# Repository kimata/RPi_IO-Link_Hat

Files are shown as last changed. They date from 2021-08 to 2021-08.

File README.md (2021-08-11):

# Raspberry Pi IO-LINK Hat

## 概要

Raspberry Pi と IO-Link 基板を接続するためのブリッジ基板です．

24V 電源で動作し，IO-Link 機器と Raspberry Pi への電源の供給を行います．

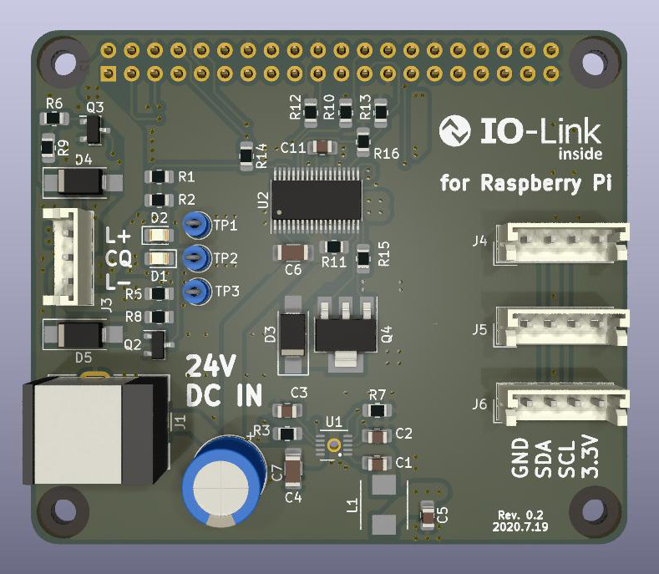
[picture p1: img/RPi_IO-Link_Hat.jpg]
Raspberry Pi IO-LINK Hat


## 使用部品

使用している主な部品は以下の通りです．

| リファレンス | Mouser # |
| --- | --- |
| D3 | 512-S100 |
| D4, D5 | 755-PTZTFTE2536B |
| J1 | 490-PJ-063AH |
| L1 | 810-SPM5030VT-2R2M-D |
| Q2, Q3 | 757-T2N7002BKLM |
| Q4 | 512-FQT7N10LTF |
| U1 | 584-LT8609AJDDM-5#TR |
| U2 | 584-LTC2874IFE#PBF |

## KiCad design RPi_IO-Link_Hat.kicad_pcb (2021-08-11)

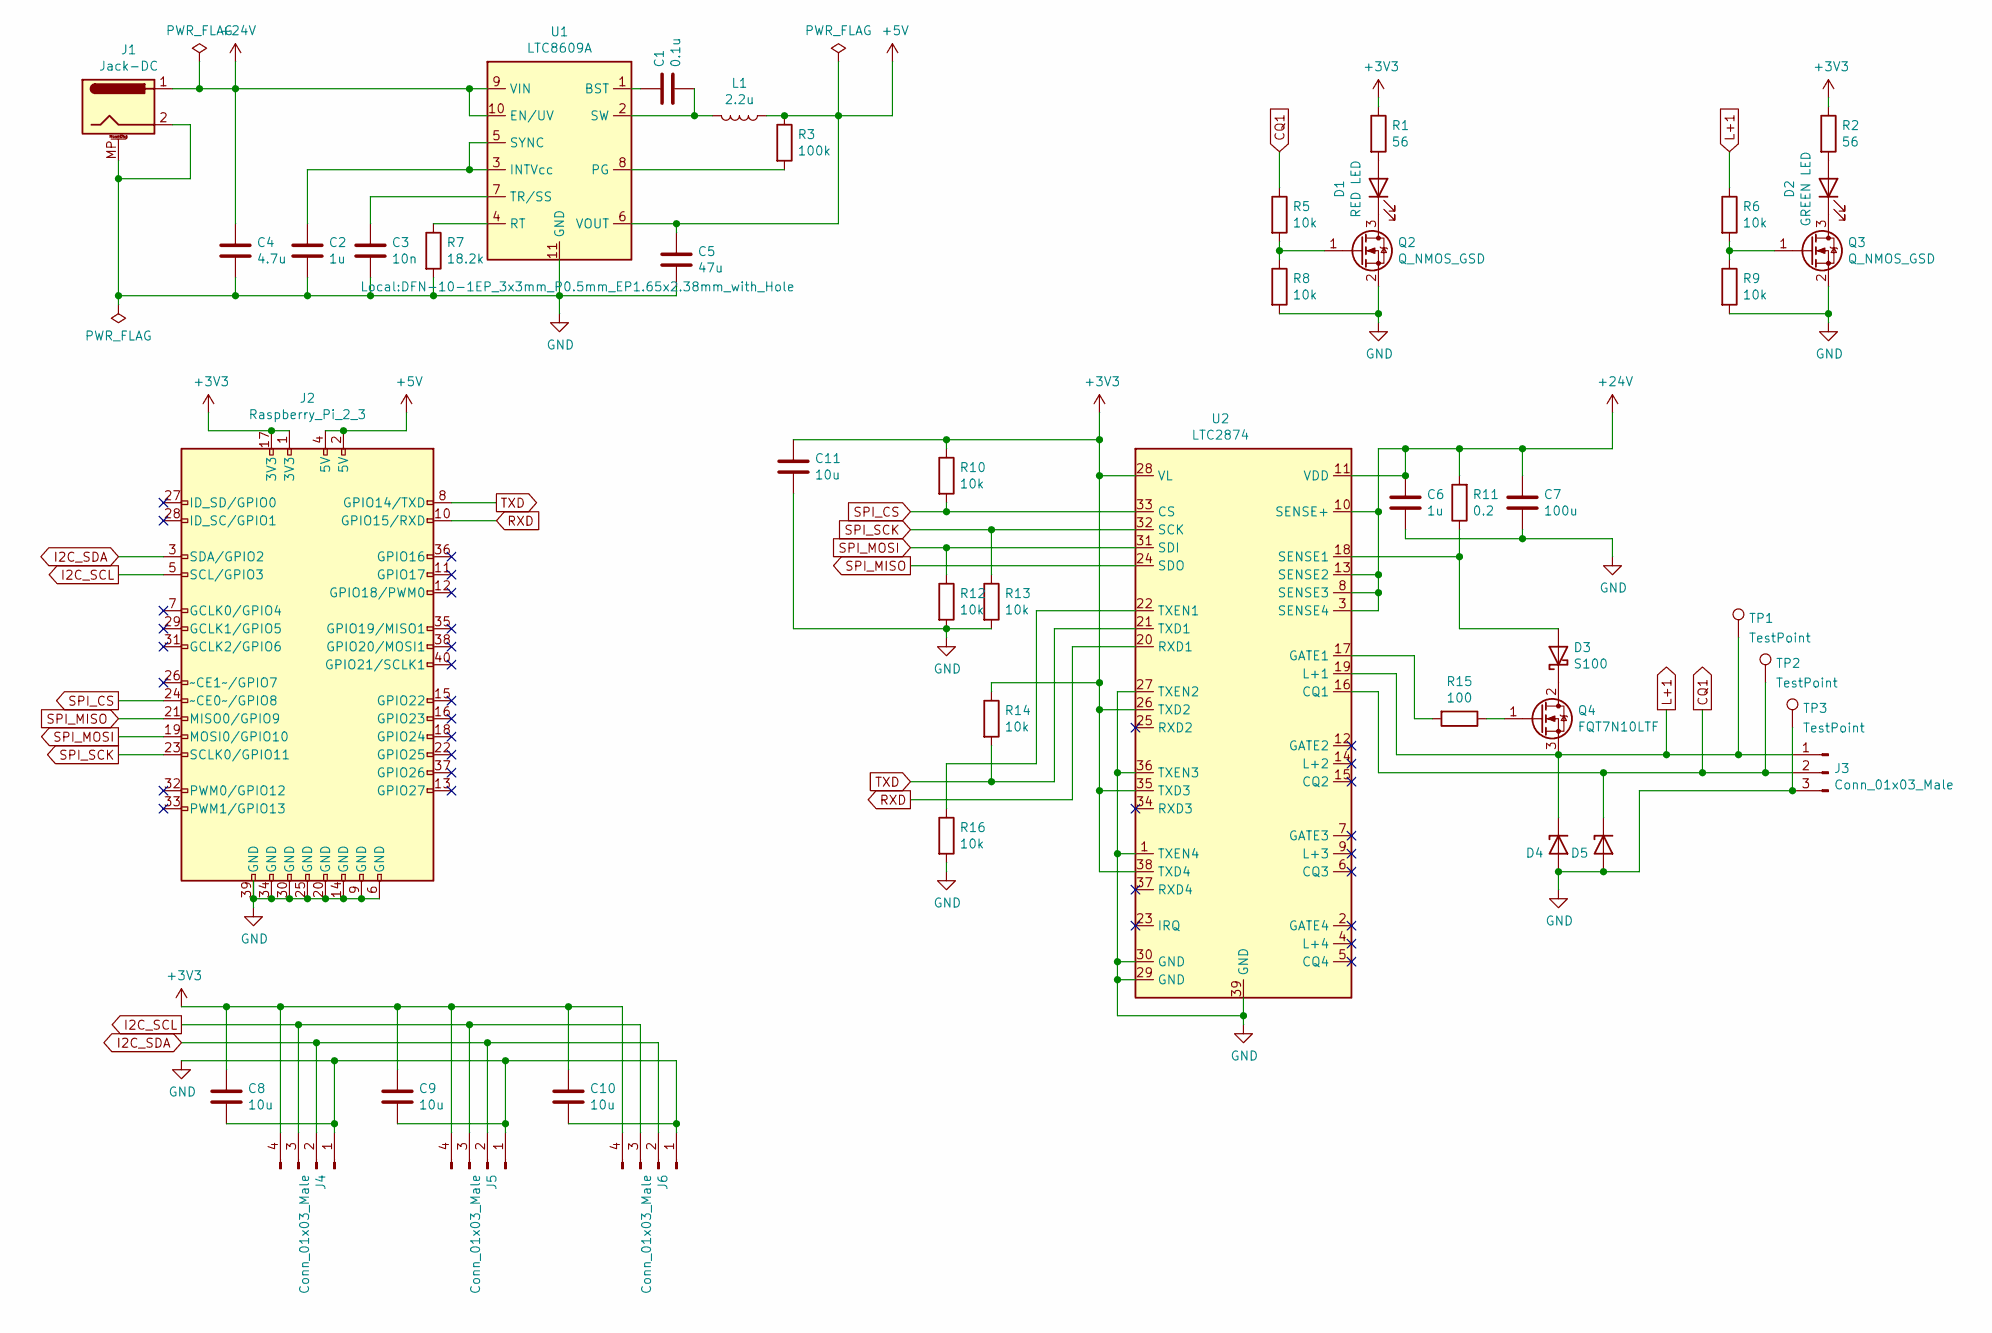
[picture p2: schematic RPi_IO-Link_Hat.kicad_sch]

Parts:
C1: 0.1u; C_0805_2012Metric_Pad1.18x1.45mm_HandSolder; Mouser 81-GCJ21BL81H104KA1L
C2: 1u; C_0805_2012Metric_Pad1.18x1.45mm_HandSolder; Mouser 81-GRM219R61A105MA1D
C3: 10n; C_0805_2012Metric_Pad1.18x1.45mm_HandSolder; Mouser 81-GCJ216R71E103KA1D
C4: 4.7u; C_1206_3216Metric_Pad1.33x1.80mm_HandSolder; Mouser 81-GRM31CR71H475KA2K
C5: 47u; C_0805_2012Metric_Pad1.18x1.45mm_HandSolder; Mouser 81-GRT21BR60J476ME3L
C6: 1u; C_1206_3216Metric_Pad1.33x1.80mm_HandSolder; Mouser 81-GRT31MC81H105KE1L
C7: 100u; CP_Radial_D8.0mm_P3.50mm; Mouser 667-EEU-EB1H101SJ
C8, C9, C10, C11: 10u; C_0805_2012Metric_Pad1.18x1.45mm_HandSolder; Mouser 81-GRM219R60J106KE9D
D1: RED LED; LED_0805_2012Metric_Pad1.15x1.40mm_HandSolder; Mouser 720-LGR971-KN-1
D2: GREEN LED; LED_0805_2012Metric_Pad1.15x1.40mm_HandSolder; Mouser 720-LSR976-NR-1
D3: S100; D_SMA_Handsoldering; Mouser 512-S100
D4, D5: PTZTFTE2536B; D_SMA_Handsoldering; Mouser 755-PTZTFTE2536B
J1: Jack-DC; BarrelJack_CUI_PJ-063AH_Horizontal; Mouser 490-PJ-063AH
J2: Raspberry_Pi_2_3; PinSocket_2x20_P2.54mm_Vertical
J3: Conn_01x03_Male; JST_EH_B3B-EH-A_1x03_P2.50mm_Vertical
J4, J5, J6: Conn_01x03_Male; JST_EH_B4B-EH-A_1x04_P2.50mm_Vertical
L1: 2.2u; L_TDK_SPM5030VT; Mouser 810-SPM5030VT-2R2M-D
Q2, Q3: Q_NMOS_GSD; SOT-23; Mouser 757-T2N7002BKLM
Q4: FQT7N10LTF; SOT-223-3_TabPin2_empty; Mouser 512-FQT7N10LTF
R1, R2: 56; R_0805_2012Metric_Pad1.20x1.40mm_HandSolder; Mouser 667-ERJ-6ENF56R0V
R3: 100k; R_0805_2012Metric_Pad1.20x1.40mm_HandSolder; Mouser 667-ERJ-6GEYJ104V
R5, R6, R8, R9, R10, R12, R13, R14, R16: 10k; R_0805_2012Metric_Pad1.20x1.40mm_HandSolder; Mouser 667-ERJ-6ENF1002V
R7: 18.2k; R_0805_2012Metric_Pad1.20x1.40mm_HandSolder; Mouser 667-ERJ-6ENF1822V
R11: 0.2; R_0805_2012Metric_Pad1.20x1.40mm_HandSolder; Mouser 667-ERJ-6BSFR20V
R15: 100; R_0805_2012Metric_Pad1.20x1.40mm_HandSolder; Mouser 667-ERJ-6ENF1000V
TP1, TP2, TP3: TestPoint; TestPoint_Loop_D1.80mm_Drill1.0mm_Beaded
U1: LTC8609A; DFN-10-1EP_3x3mm_P0.5mm_EP1.65x2.38mm_with_Hole; Mouser 584-LT8609AJDDM-5#TR
U2: LTC2874; TSSOP-38_4.4x9.7mm_P0.5mm_with_Hole; Mouser 584-LTC2874IFE#PBF

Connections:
+3V3: C8.1, C9.1, C10.1, C11.1, J2.1 (3V3), J2.17 (3V3), J4.4, J5.4, J6.4, R1.1, R2.1, R10.1, R14.1, U2.26 (TXD2), U2.28 (VL), U2.35 (TXD3), U2.38 (TXD4)
+5V: C5.1, J2.2 (5V), J2.4 (5V), L1.1, R3.1, U1.6 (VOUT)
+24V: C4.1, C6.1, C7.1, J1.1, R11.2, U1.9 (VIN), U1.10 (EN/UV), U2.3 (SENSE4), U2.8 (SENSE3), U2.10 (SENSE+), U2.11 (VDD), U2.13 (SENSE2)
CQ1: D5.1 (K), J3.2, R5.1, TP2.1, U2.16 (CQ1)
GND: C2.2, C3.2, C4.2, C5.2, C6.2, C7.2, C8.2, C9.2, C10.2, C11.2, D4.2 (A), D5.2 (A), J1.2, J1.MP (MountPin), J2.6 (GND), J2.9 (GND), J2.14 (GND), J2.20 (GND), J2.25 (GND), J2.30 (GND), J2.34 (GND), J2.39 (GND), J3.3, J4.1, J5.1, J6.1, Q2.2 (S), Q3.2 (S), R7.2, R8.2, R9.2, R12.2, R13.2, R16.2, TP3.1, U1.11 (GND), U2.1 (TXEN4), U2.27 (TXEN2), U2.29 (GND), U2.30 (GND), U2.36 (TXEN3), U2.39 (GND)
I2C_SCL: J2.5 (SCL/GPIO3), J4.3, J5.3, J6.3
I2C_SDA: J2.3 (SDA/GPIO2), J4.2, J5.2, J6.2
L+1: D4.1 (K), J3.1, Q4.3 (S), R6.1, TP1.1, U2.19 (L+1)
unnamed: C1.1, U1.1 (BST)
unnamed: C1.2, L1.2, U1.2 (SW)
unnamed: C2.1, U1.3 (INTVcc), U1.5 (SYNC)
unnamed: C3.1, U1.7 (TR/SS)
unnamed: D1.1 (K), Q2.3 (D)
unnamed: D1.2 (A), R1.2
unnamed: D2.1 (K), Q3.3 (D)
unnamed: D2.2 (A), R2.2
unnamed: D3.1 (K), Q4.2 (D)
unnamed: D3.2 (A), R11.1, U2.18 (SENSE1)
unnamed: Q2.1 (G), R5.2, R8.1
unnamed: Q3.1 (G), R6.2, R9.1
unnamed: Q4.1 (G), R15.1
unnamed: R3.2, U1.8 (PG)
unnamed: R7.1, U1.4 (RT)
unnamed: R15.2, U2.17 (GATE1)
unnamed: R16.1, U2.22 (TXEN1)
RXD: J2.10 (GPIO15/RXD), U2.20 (RXD1)
SPI_CS: J2.24 (~CE0~/GPIO8), R10.2, U2.33 (CS)
SPI_MISO: J2.21 (MISO0/GPIO9), U2.24 (SDO)
SPI_MOSI: J2.19 (MOSI0/GPIO10), R12.1, U2.31 (SDI)
SPI_SCK: J2.23 (SCLK0/GPIO11), R13.1, U2.32 (SCK)
TXD: J2.8 (GPIO14/TXD), R14.2, U2.21 (TXD1)

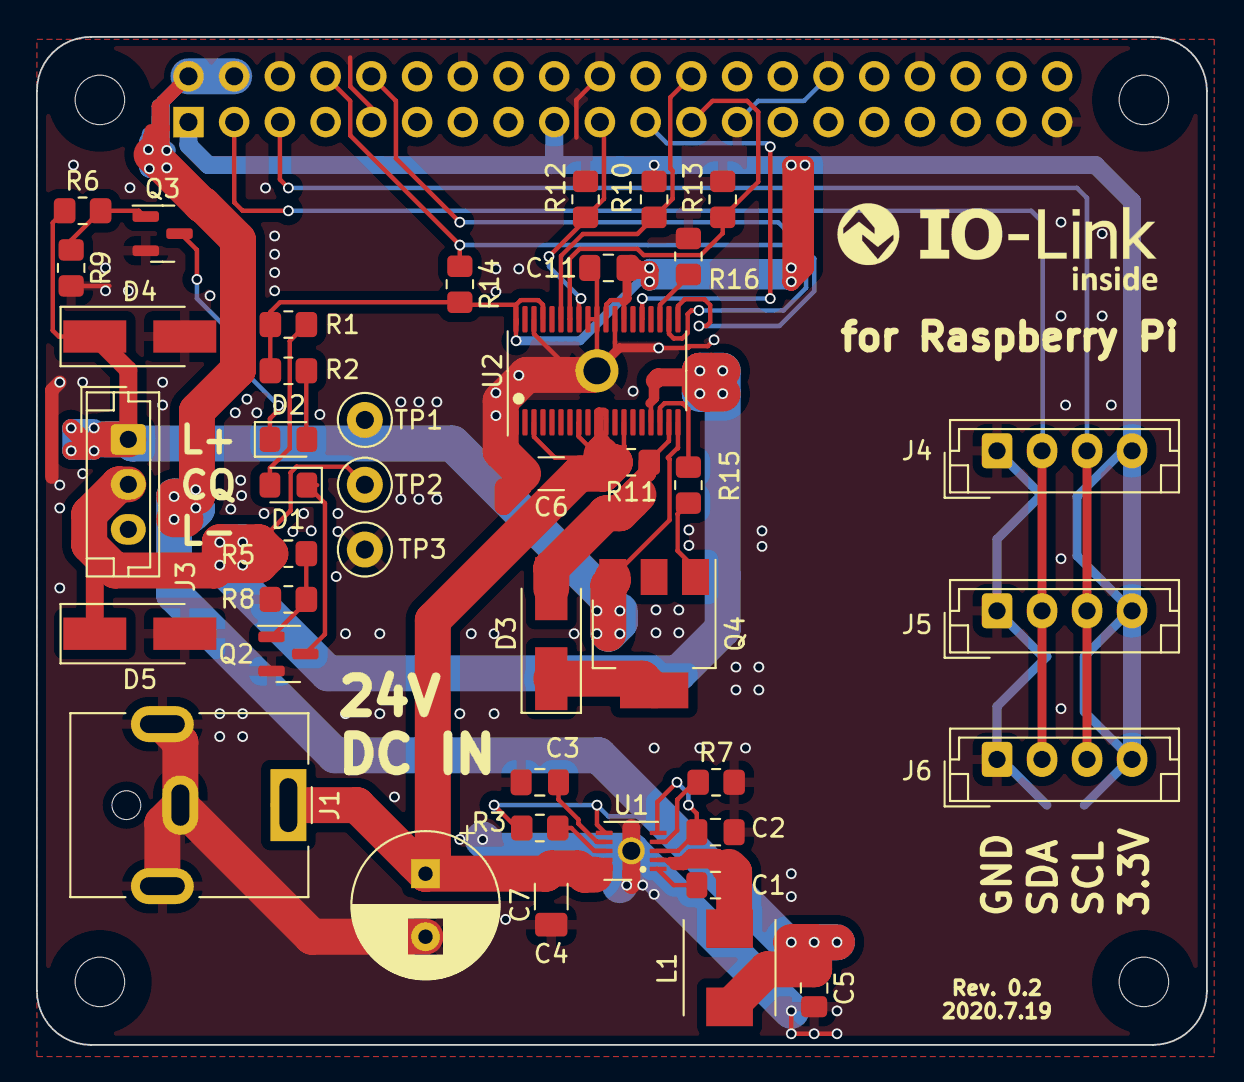
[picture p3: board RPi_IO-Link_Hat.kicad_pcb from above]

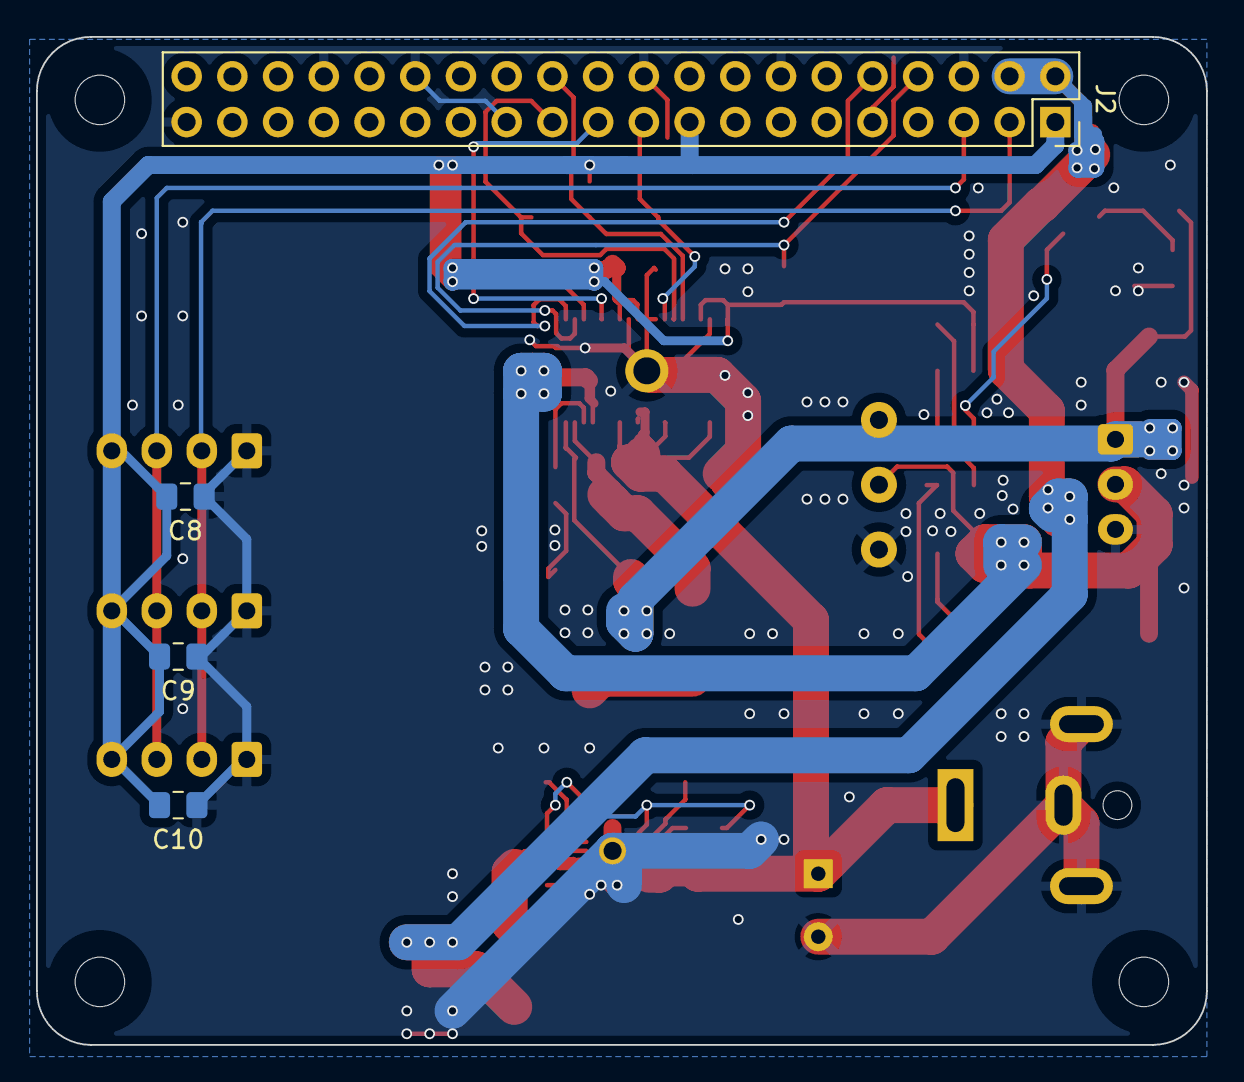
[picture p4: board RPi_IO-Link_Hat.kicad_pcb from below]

Board: 2 copper layers, 65.0 x 56.0 mm, 46 parts (4 on the bottom side), 31 nets.

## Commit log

2021-07-04 feat: とりあえず完成
    [RaspberryPi_IO-Link_Hat.kicad_pcb, RaspberryPi_IO-Link_Hat.sch]
2021-07-04 fix: KiCad 5.99 に移行
    [RaspberryPi_IO-Link_Hat.kicad_pcb]
2021-07-04 fix: Mouser に在庫がある部品に置き換え
    [RaspberryPi_IO-Link_Hat.sch]
2021-07-04 fix: ライブラリの参照がおかしくなっていた問題を修正
    [RaspberryPi_IO-Link_Hat.kicad_pcb]
2021-07-04 fix: KiCad 5.99 に追従
    [RaspberryPi_IO-Link_Hat.kicad_sch, RaspberryPi_IO-Link_Hat.sch]
2021-07-04 fix: 電流検出抵抗を 2012 サイズに変更
    [RaspberryPi_IO-Link_Hat.kicad_sch]
2021-07-05 fix: 名前を変更
    [RPi_IO-Link_Hat.kicad_pcb, RPi_IO-Link_Hat.kicad_sch]
2021-07-11 fix: ライブラリパスの設定を追加
2021-07-19 fix: 改善 - CQ H で LED を点灯させるようにした - TP を追加
    [RPi_IO-Link_Hat.kicad_pcb, RPi_IO-Link_Hat.kicad_sch]
2021-08-11 fix: 手はんだしやすくするため，LTC8609A のランドサイズを少し拡大
    [RPi_IO-Link_Hat.kicad_pcb]
2021-08-11 feat: 基板製造用のファイルを登録
    [RPi_IO-Link_Hat-B_Cu.gbl, RPi_IO-Link_Hat-B_Mask.gbs, RPi_IO-Link_Hat-B_Silkscreen.gbo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]
2021-08-11 doc: ドキュメントを追加
